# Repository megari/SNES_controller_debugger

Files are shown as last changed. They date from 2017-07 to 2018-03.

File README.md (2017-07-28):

SNES controller debugger
========================

This is a little project for debugging SNES controllers. The PCB design files
and the firmware source code are included.

The hardware uses an Atmel mega32u4 microcontroller.

The firmware uses the [YAAL](https://github.com/raphendyr/yaal) library and
[yaamake](https://github.com/raphendyr/yaamake). These are included as
submodules in the firmware/vendor directory.

Compilation of the firmware
---------------------------

The avr-gcc toolchain is required in order to compile the firmware. The
repositories of your distribution probably have this available.

After the toolchain has been installed:
```sh
cd firmware
```

If you haven't built yaamake yet, do so:
```sh
cd vendor/yaamake
make
cd ../..
```

Finally, build the firmware and program the board:
```sh
nano Makefile # Check that the programmer port is correct
make
make program
```

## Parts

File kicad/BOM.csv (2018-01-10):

Id | Designator | Package | Quantity | Designation | Supplier and ref
1 | H4,H3,H2,H1 | MountingHole_3.4mm | 4
2 | U1 | TQFP-44_10x10mm_Pitch0.8mm | 1 | ATmega32U4
3 | C1,C6 | C_0603_HandSoldering | 2 | 0.1µF
4 | C2,C3 | C_0603_HandSoldering | 2 | 22pF
5 | C4,C5,C7 | C_0603_HandSoldering | 3 | 1µF
6 | R1 | R_0603_HandSoldering | 1 | 10k
7 | R2,R3 | R_0805_HandSoldering | 2 | 22
8 | RV1 | Potentiometer_Trimmer_Vishay_TS53YL | 1 | POT
9 | D1,D2 | D_SOD-123 | 2 | MBR0520
10 | F1 | R_0603_HandSoldering | 1 | 500mA
11 | SW1 | SW_PUSH_6mm | 1 | Reset
12 | Y1 | Crystal_SMD_5032-2pin_5.0x3.2mm_HandSoldering | 1 | 16MHz
13 | R4,R8 | R_0603_HandSoldering | 2 | 1M
14 | R5,R7 | R_0603_HandSoldering | 2 | 220
15 | R6 | R_0603_HandSoldering | 1 | 0
16 | DS1 | LCD_2004_Pitch2.54mm | 1 | LCD20X4
17 | J2 | SNES_controller_port | 1 | Controller
18 | J1 | Pin_Header_Straight_2x03_Pitch2.54mm | 1 | ICSP
19 | Q1 | SOT-23_Handsoldering | 1 | DMG2302UK-7
20 | Q2 | SOT-23_Handsoldering | 1 | DMP2215L-7
21 | J3 | Conn_USBmicro-B_Amphenol_10118194-0001LF | 1 | MICRO_USB

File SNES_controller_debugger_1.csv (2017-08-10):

Id | Designator | Package | Quantity | Designation | Supplier and ref
1 | DS1 | LCD_2004_Pitch2.54mm | 1 | LCD20X4
2 | J1 | Pin_Header_Straight_2x03_Pitch2.54mm | 1 | ICSP
3 | U1 | TQFP-44_10x10mm_Pitch0.8mm | 1 | ATmega32U4
4 | C1,C6 | C_0603_HandSoldering | 2 | 0.1µF
5 | C2,C3 | C_0603_HandSoldering | 2 | 22pF
6 | C4,C5,C7 | C_0603_HandSoldering | 3 | 1µF
7 | J3 | Conn_USBmicro-B_Amphenol_10118194-0001LF | 1 | MICRO_USB
8 | R1 | R_0603_HandSoldering | 1 | 10k
9 | R2,R3 | R_0805_HandSoldering | 2 | 22
10 | RV1 | Potentiometer_Trimmer_Vishay_TS53YL | 1 | POT
11 | J2 | SNES_controller_port | 1 | CONTROLLER_OUT
12 | D1,D2 | D_SOD-123 | 2 | MBR0520
13 | F1 | R_0603_HandSoldering | 1 | 500mA
14 | SW1 | SW_PUSH_6mm | 1 | Reset_switch
15 | Y1 | Crystal_SMD_5032-2pin_5.0x3.2mm_HandSoldering | 1 | 16MHz
16 | Q1,Q2 | SOT-23 | 2 | DMG2302UK-7
17 | R4,R8 | R_0603_HandSoldering | 2 | 1M
18 | R5,R7 | R_0603_HandSoldering | 2 | 220
19 | R6 | R_0603_HandSoldering | 1 | 0

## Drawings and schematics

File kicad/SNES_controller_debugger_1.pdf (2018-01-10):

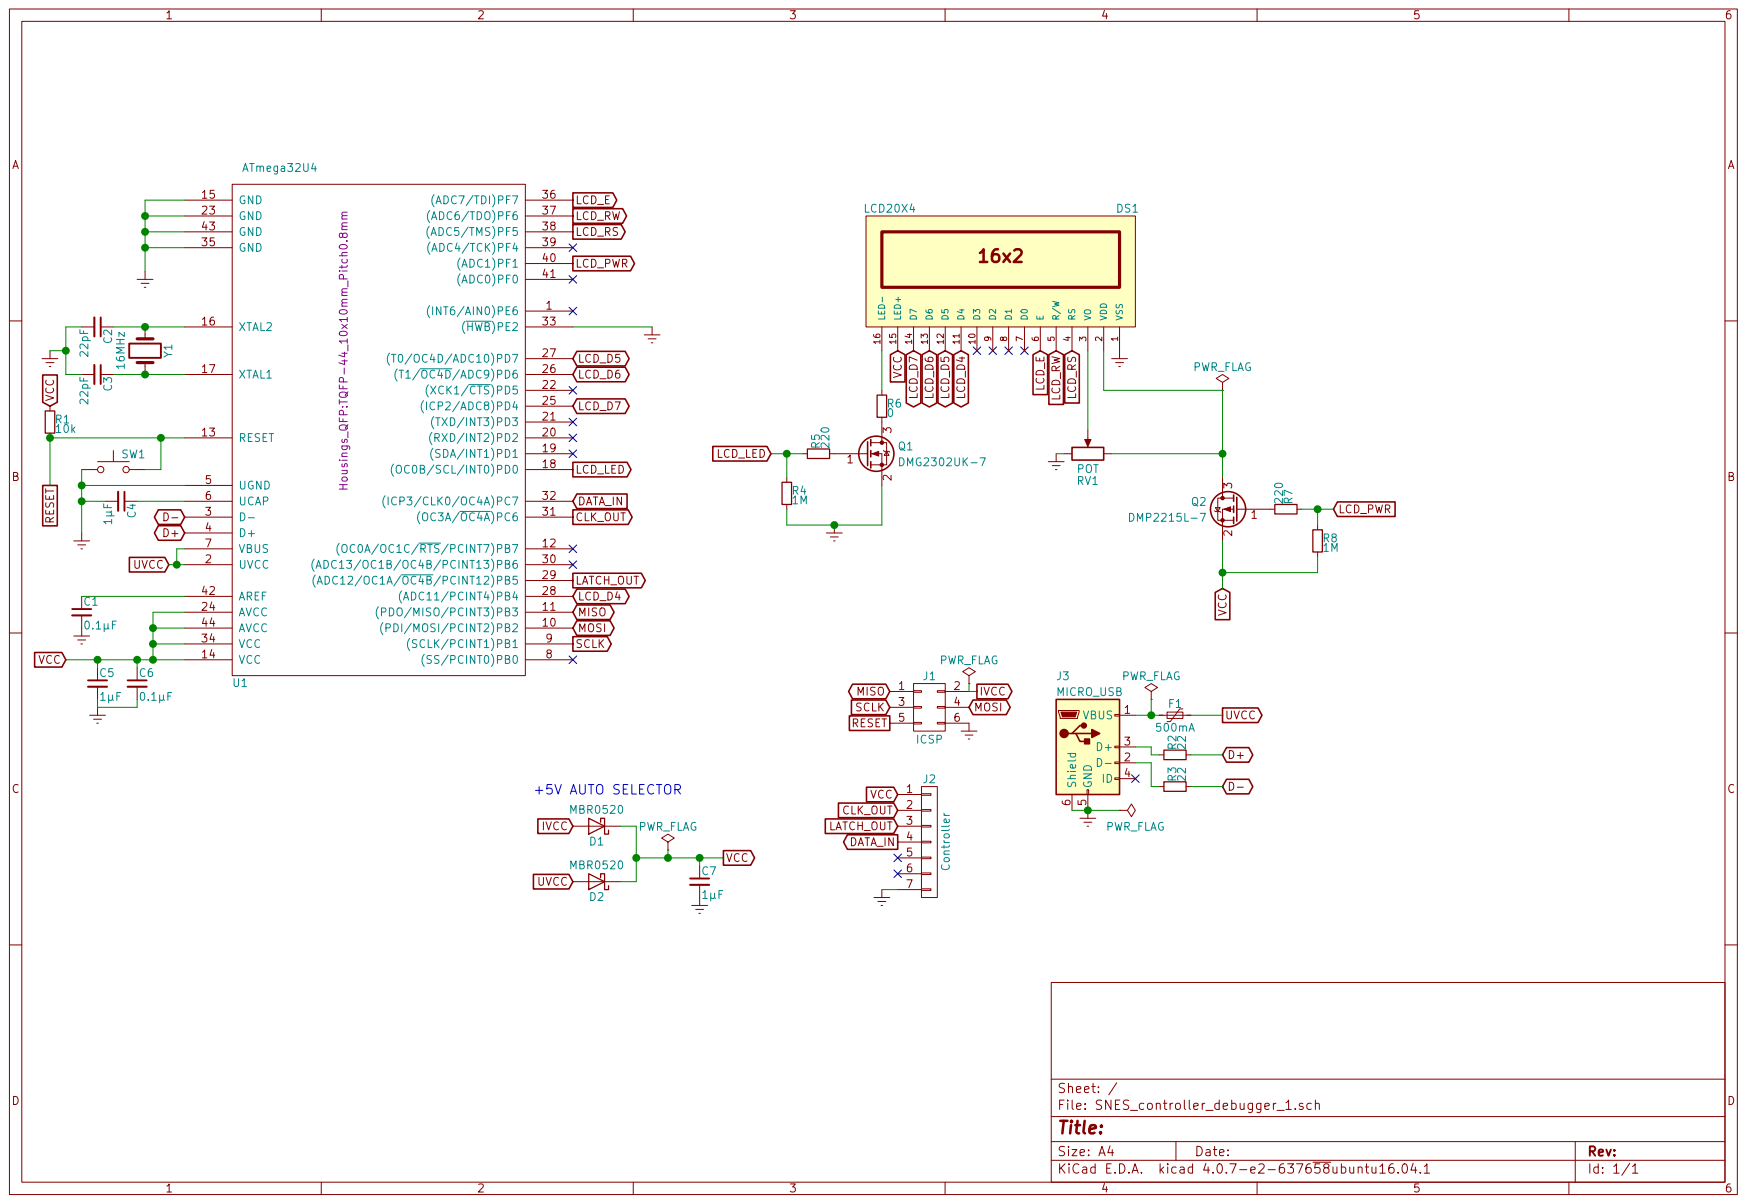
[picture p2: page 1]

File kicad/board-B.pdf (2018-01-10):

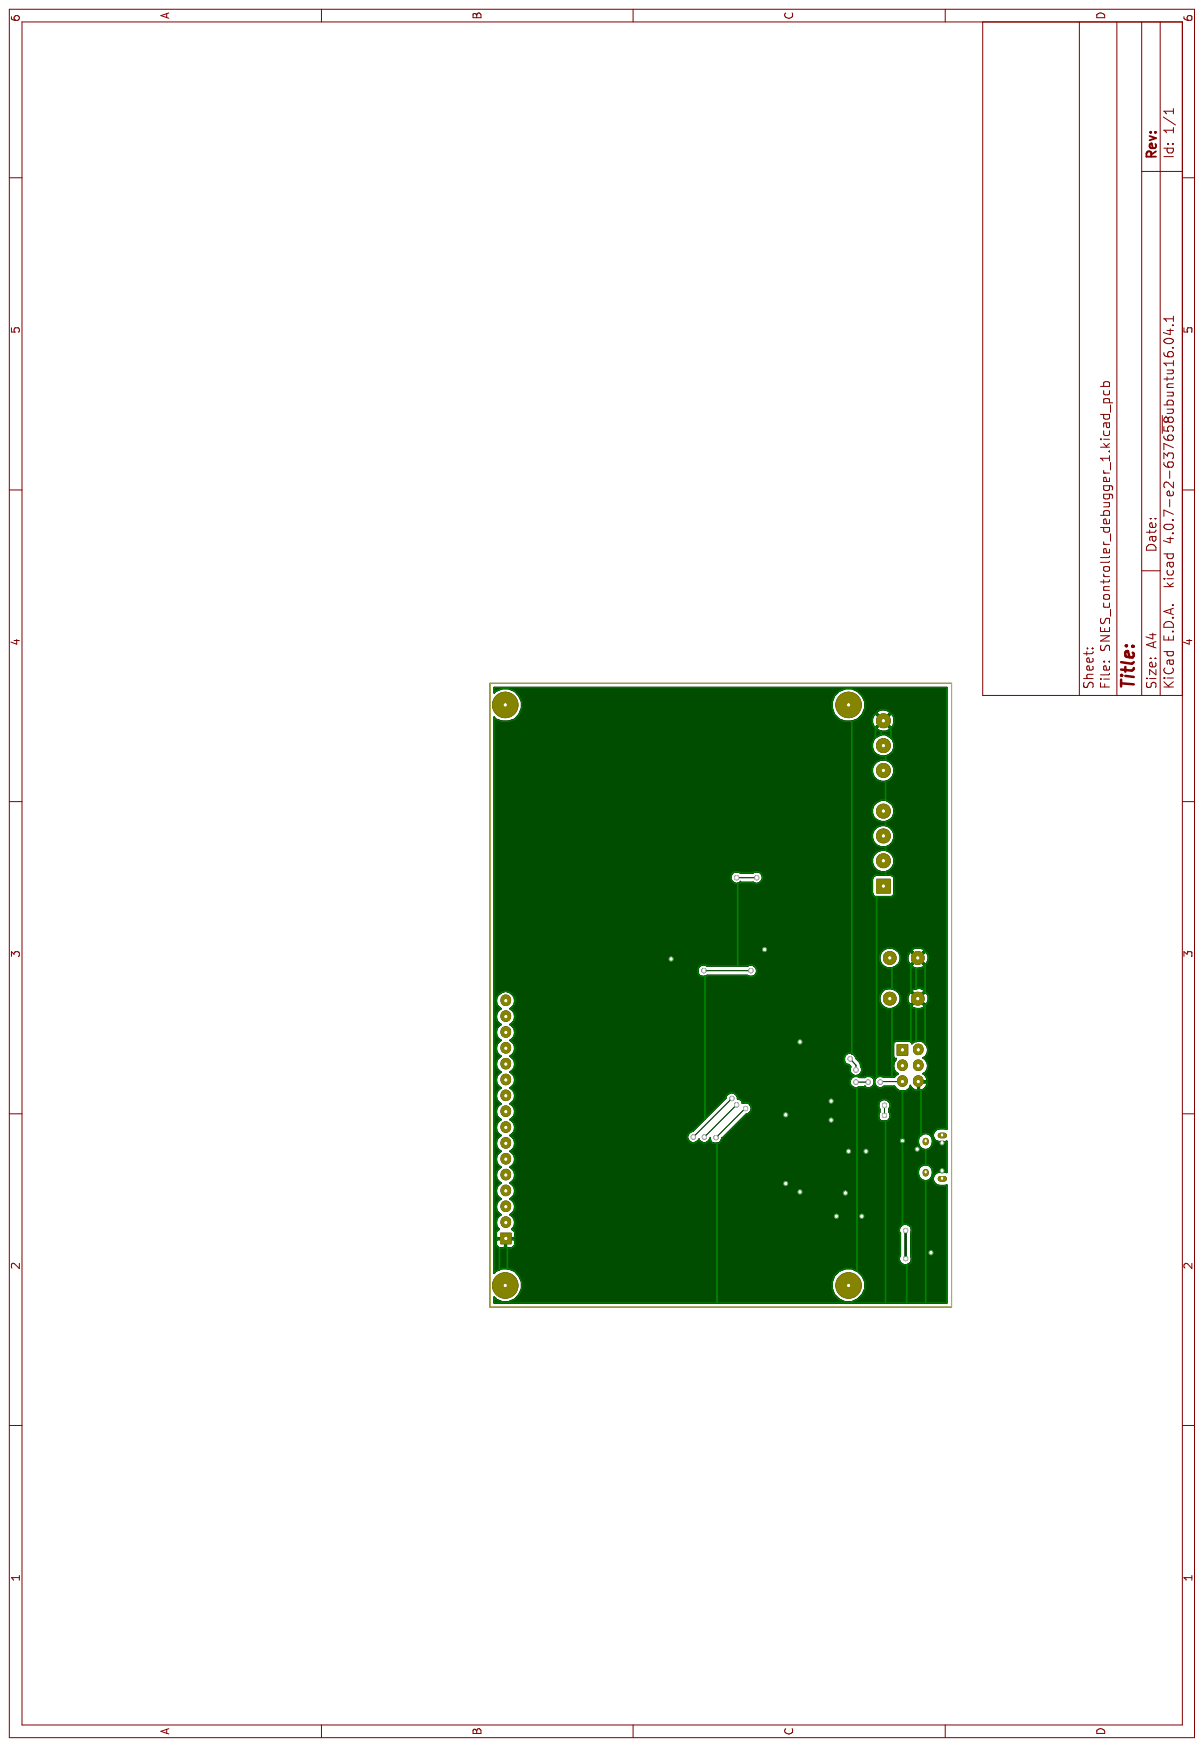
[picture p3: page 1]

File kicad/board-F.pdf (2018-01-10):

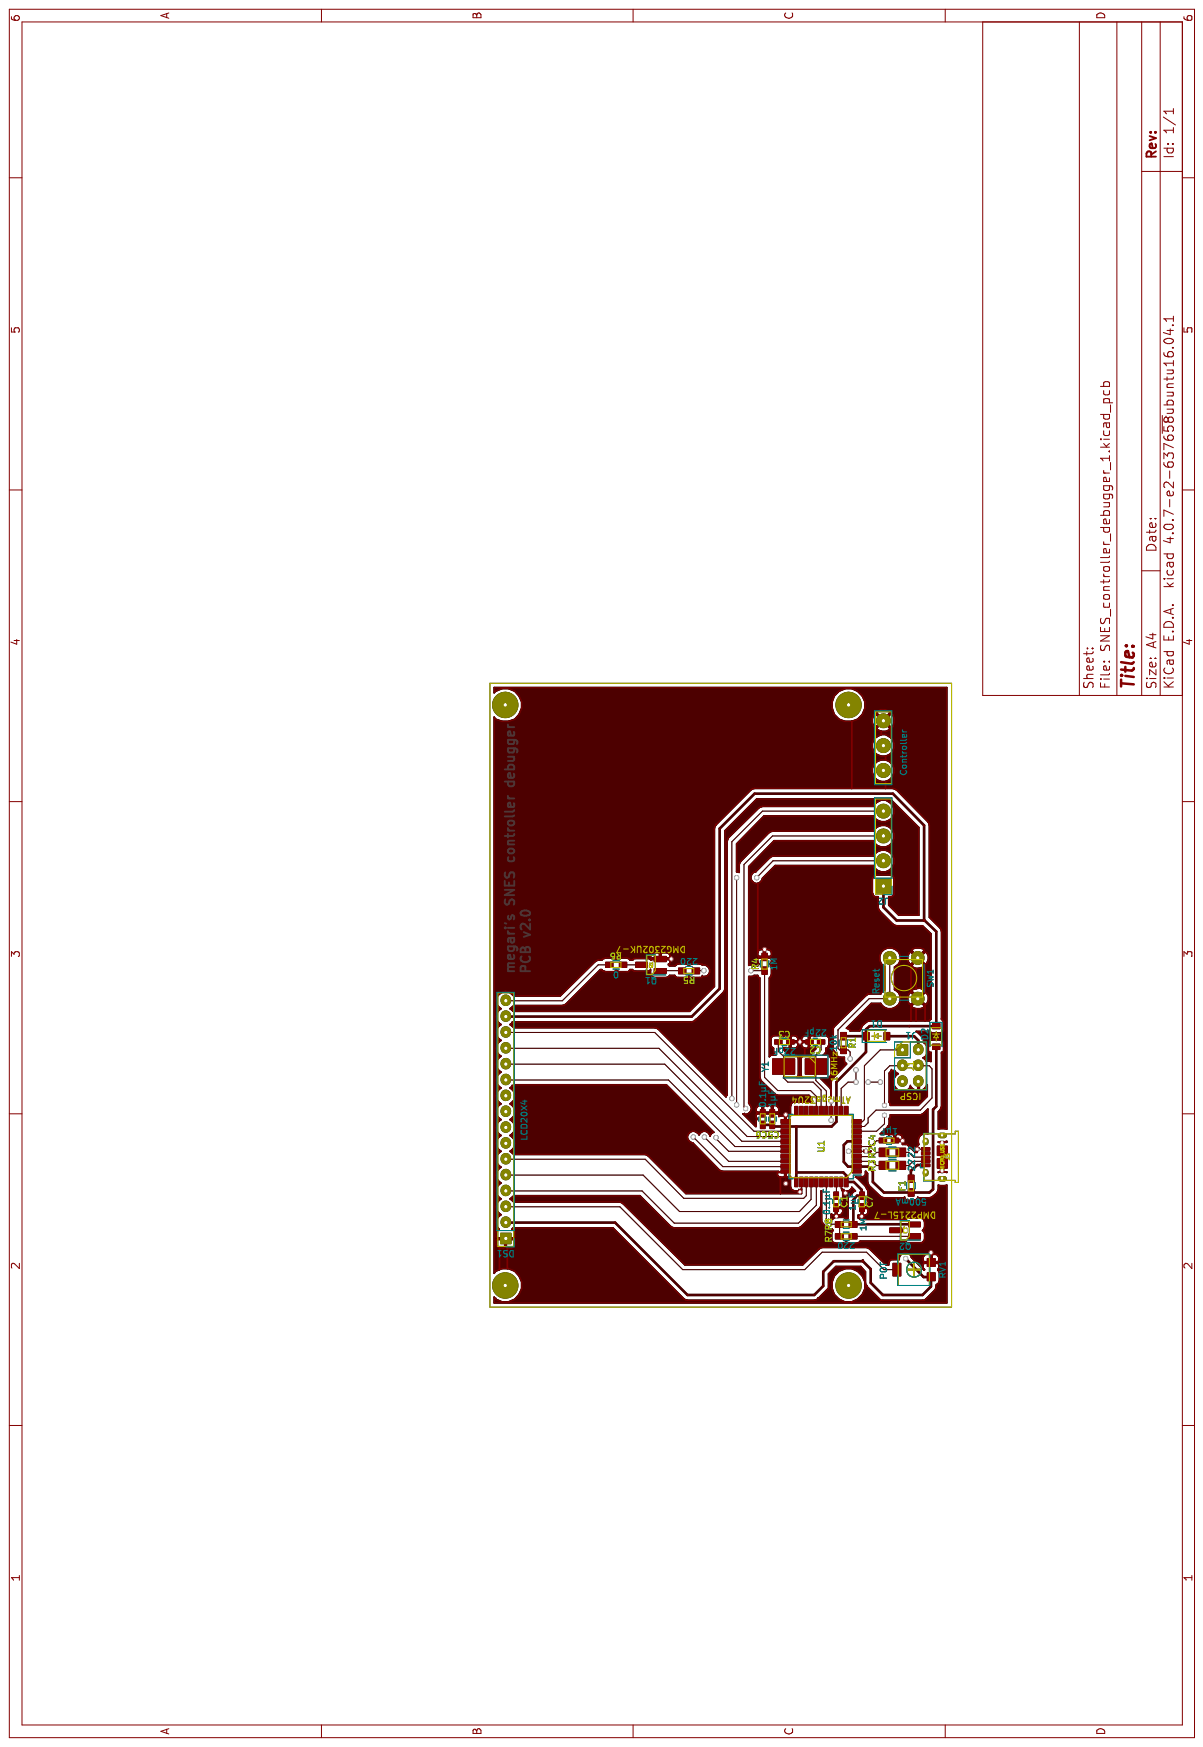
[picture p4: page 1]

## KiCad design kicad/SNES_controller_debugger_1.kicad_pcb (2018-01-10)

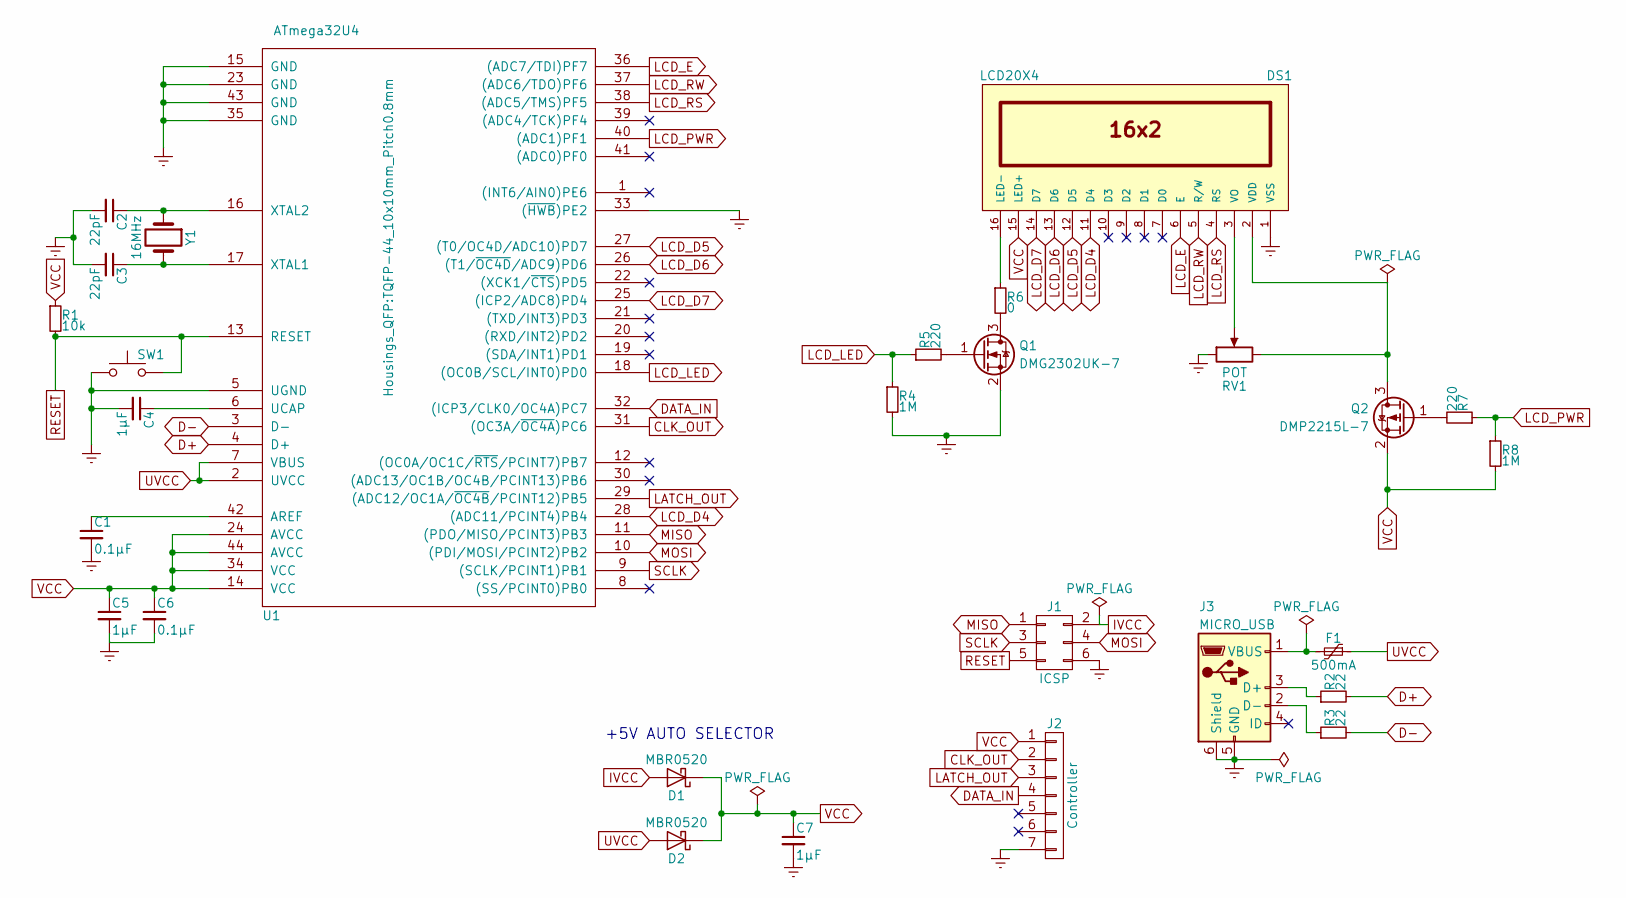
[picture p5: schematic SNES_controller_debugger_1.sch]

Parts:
C1, C6: 0.1µF; C_0603_HandSoldering
C2, C3: 22pF; C_0603_HandSoldering
C4, C5, C7: 1µF; C_0603_HandSoldering
D1, D2: MBR0520; D_SOD-123
DS1: LCD20X4; LCD_2004_Pitch2.54mm
F1: 500mA; R_0603_HandSoldering
J1: ICSP; Pin_Header_Straight_2x03_Pitch2.54mm
J2: Controller; SNES_controller_port
J3: MICRO_USB; Conn_USBmicro-B_Amphenol_10118194-0001LF; MPN 10118194-0001LF; Digi-Key part number 609-4618-1-ND
Q1: DMG2302UK-7; SOT-23_Handsoldering
Q2: DMP2215L-7; SOT-23_Handsoldering
R1: 10k; R_0603_HandSoldering
R2, R3: 22; R_0805_HandSoldering
R4, R8: 1M; R_0603_HandSoldering
R5, R7: 220; R_0603_HandSoldering
R6: 0; R_0603_HandSoldering
RV1: POT; Potentiometer_Trimmer_Vishay_TS53YL; MPN TS53YL103MR10; Digi-Key part number TS53YL-10KCT-ND
SW1: Reset; SW_PUSH_6mm; MPN MJTP1230; Digi-Key part number 679-2428-ND
U1: ATmega32U4; TQFP-44_10x10mm_Pitch0.8mm; MPN ATMEGA32U4-AU; Digi-Key part number ATMEGA32U4-AU-ND
Y1: 16MHz; Crystal_SMD_5032-2pin_5.0x3.2mm_HandSoldering; MPN NX5032GA-16MHZ-STD-CSK-4; Digi-Key part number 644-1187-1-ND

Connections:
CLK_OUT: J2.2, U1.31 ((OC3A/~OC4A~)PC6)
D+: R2.2, U1.4 (D+)
D-: R3.2, U1.3 (D-)
DATA_IN: J2.4, U1.32 ((ICP3/CLK0/OC4A)PC7)
Earth: C1.2, C2.2, C3.2, C4.2, C5.2, C6.2, C7.2, DS1.1 (VSS), J1.6, J2.7, J3.5 (GND), J3.6 (Shield), Q1.2 (S), R4.2, RV1.1, SW1.1, U1.5 (UGND), U1.15 (GND), U1.23 (GND), U1.33 ((~HWB~)PE2), U1.35 (GND), U1.43 (GND)
IVCC: D1.2 (A), J1.2
LATCH_OUT: J2.3, U1.29 ((ADC12/OC1A/~OC4B~/PCINT12)PB5)
LCD_D4: DS1.11 (D4), U1.28 ((ADC11/PCINT4)PB4)
LCD_D5: DS1.12 (D5), U1.27 ((T0/OC4D/ADC10)PD7)
LCD_D6: DS1.13 (D6), U1.26 ((T1/~OC4D~/ADC9)PD6)
LCD_D7: DS1.14 (D7), U1.25 ((ICP2/ADC8)PD4)
LCD_E: DS1.6 (E), U1.36 ((ADC7/TDI)PF7)
LCD_LED: R4.1, R5.1, U1.18 ((OC0B/SCL/INT0)PD0)
LCD_PWR: R7.1, R8.1, U1.40 ((ADC1)PF1)
LCD_RS: DS1.4 (RS), U1.38 ((ADC5/TMS)PF5)
LCD_RW: DS1.5 (R/W), U1.37 ((ADC6/TDO)PF6)
MISO: J1.1, U1.11 ((PDO/MISO/PCINT3)PB3)
MOSI: J1.4, U1.10 ((PDI/MOSI/PCINT2)PB2)
unnamed: C1.1, U1.42 (AREF)
unnamed: C2.1, U1.16 (XTAL2), Y1.1
unnamed: C3.1, U1.17 (XTAL1), Y1.2
unnamed: C4.1, U1.6 (UCAP)
unnamed: DS1.2 (VDD), Q2.3 (D), RV1.3
unnamed: DS1.3 (VO), RV1.2
unnamed: DS1.16 (LED-), R6.1
unnamed: F1.2, J3.1 (VBUS)
unnamed: J3.2 (D-), R3.1
unnamed: J3.3 (D+), R2.1
unnamed: Q1.1 (G), R5.2
unnamed: Q1.3 (D), R6.2
unnamed: Q2.1 (G), R7.2
RESET: J1.5, R1.2, SW1.2, U1.13 (RESET)
SCLK: J1.3, U1.9 ((SCLK/PCINT1)PB1)
UVCC: D2.2 (A), F1.1, U1.2 (UVCC), U1.7 (VBUS)
VCC: C5.1, C6.1, C7.1, D1.1 (K), D2.1 (K), DS1.15 (LED+), J2.1, Q2.2 (S), R1.1, R8.2, U1.14 (VCC), U1.24 (AVCC), U1.34 (VCC), U1.44 (AVCC)

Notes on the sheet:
+5V AUTO SELECTOR

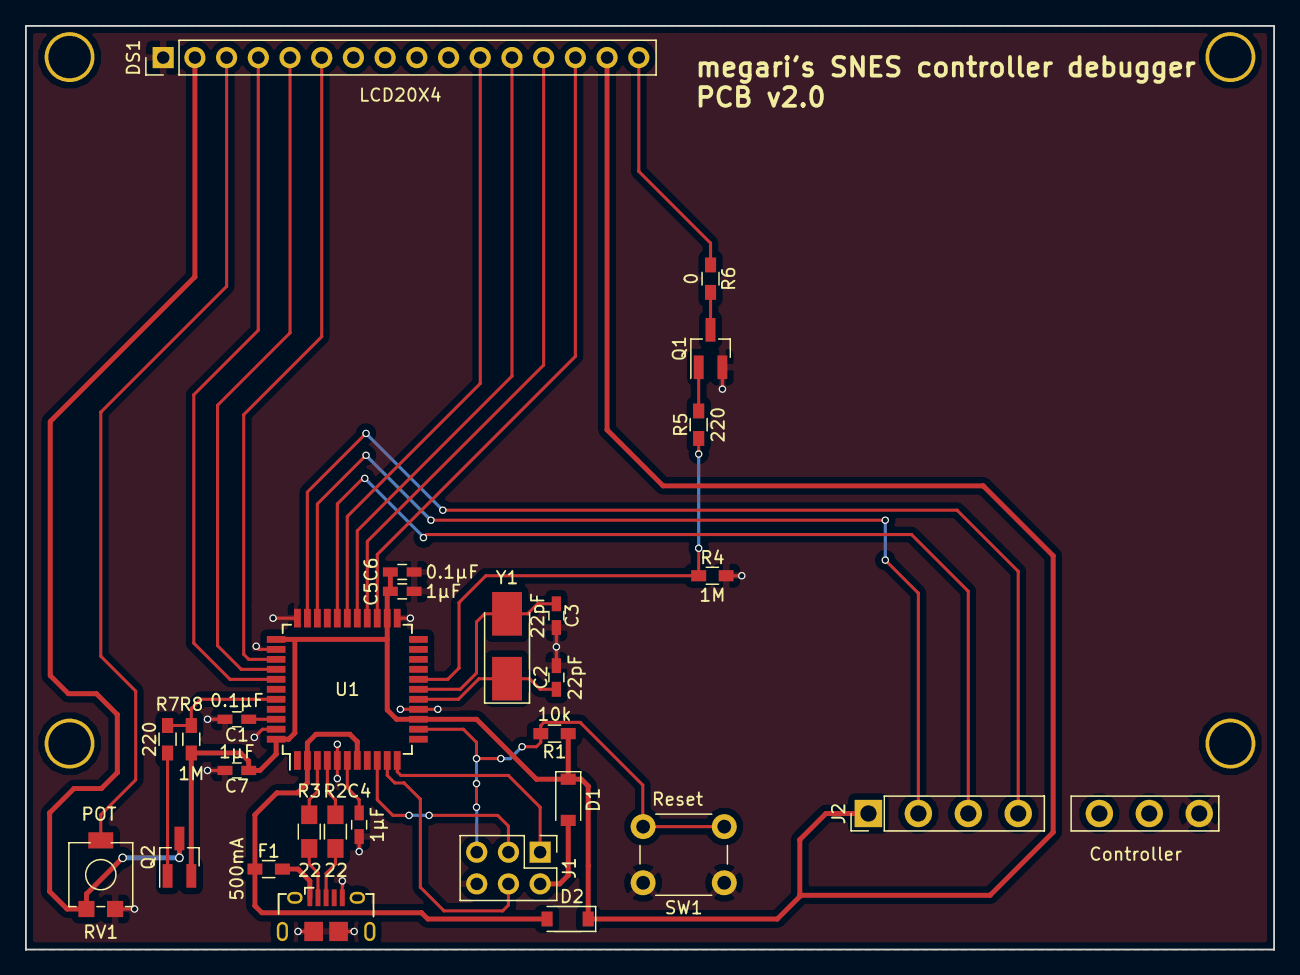
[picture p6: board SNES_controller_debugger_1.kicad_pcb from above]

Board: 2 copper layers, 100.0 x 74.0 mm, 32 parts (0 on the bottom side), 35 nets.

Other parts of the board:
H1, H2, H3, H4: MountingHole_3.4mm

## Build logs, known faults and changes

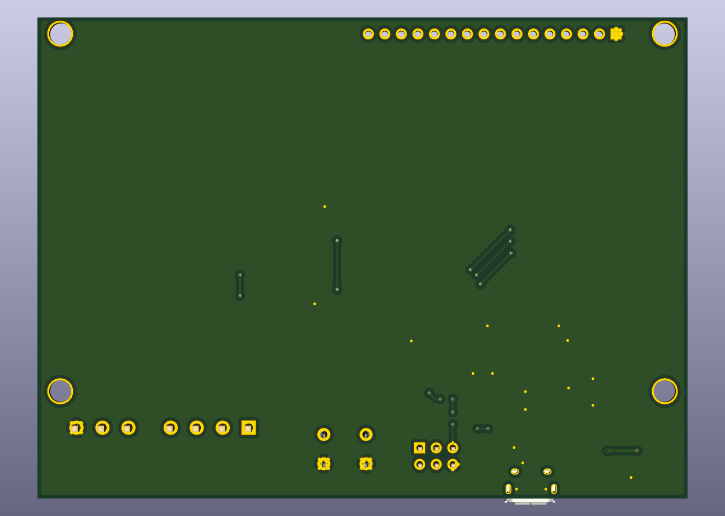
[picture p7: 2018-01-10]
kicad/SNES_controller_debugger_1_back.png

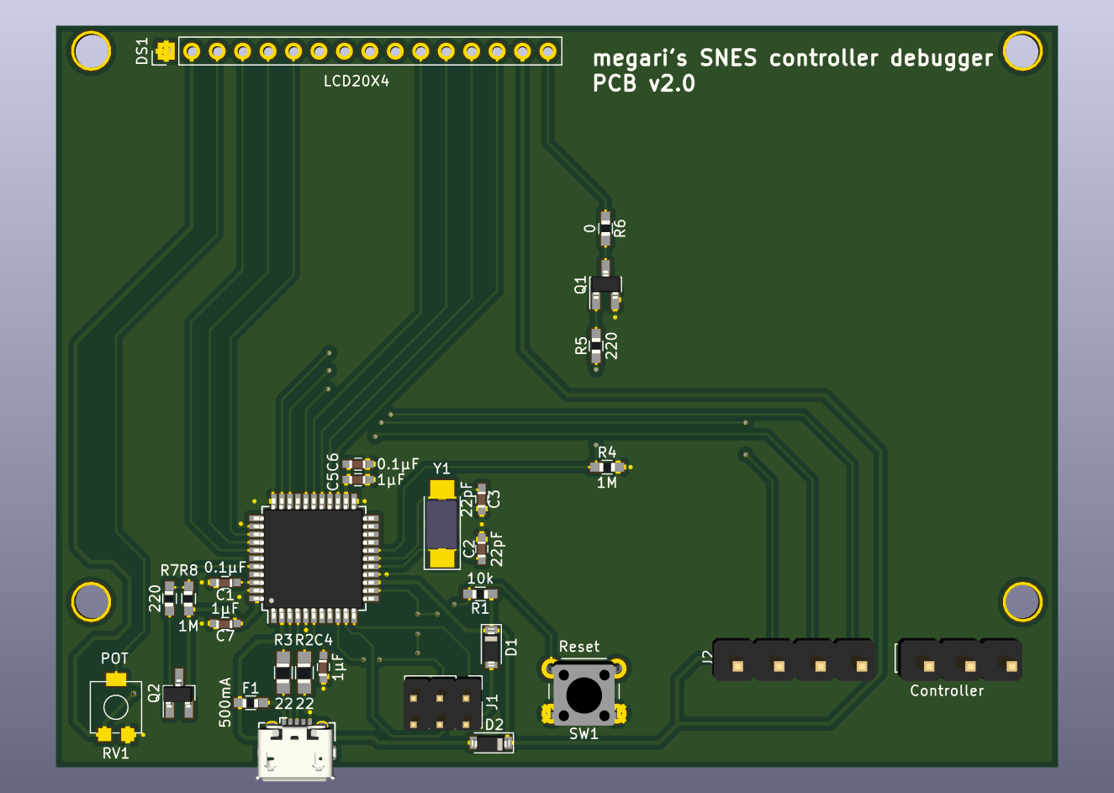
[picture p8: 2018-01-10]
kicad/SNES_controller_debugger_1_front.png

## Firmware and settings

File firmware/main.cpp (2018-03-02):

#include <yaal/io/ports.hh>
#include <yaal/devices/lcd_hd44780.hh>
#include <yaal/types/pinset.hh>

using namespace yaal;

template<typename PIN, bool polarity = true>
class PowerPin {
    PIN pin;

public:
    PowerPin() {
        pin.mode = OUTPUT;
        pin = polarity; // Initially on
    }

    void power(bool on) {
        /*
         * Truth table:
         *
         * polarity |  on | polarity ^ on | pin | power
         * ---------+-----+---------------+-----+------
         *     T    |  T  |       F       |  T  |  ON
         *     T    |  F  |       T       |  F  |  OFF
         *     F    |  T  |       T       |  F  |  ON
         *     F    |  F  |       F       |  T  |  OFF
         *
         */
        pin = !(polarity ^ on);
    }
};

template<bool polarity>
class PowerPin<NullPin, polarity> {
public:
    void power(bool) { }
};

class Backlight {
    uint8_t value;
    PortD0 pin;

    void reset(uint8_t val) {
        pin.mode = OUTPUT;

        // Fast PWM, non-inverting mode on OC0B (PortD0).
        // Use a prescaler of 64 to get a bit shy of 1000 Hz.
        TCCR0A = _BV(COM0B1) | _BV(WGM00) | _BV(WGM01);
        TCCR0B = 0;
        TCNT0 = 0;
        value = val;
        OCR0B = val;
        TCCR0B = _BV(CS00) | _BV(CS01);
    }
public:
    Backlight(uint8_t val = 0xff) : value(val) {
        reset(value);
    }

    void set(uint8_t val) {
        if (val == 0) { // Avoid the single spike
            TCCR0A = 0;
            TCCR0B = 0;
            pin = false;
            value = val;
        }
        else if (value == 0)
            reset(val);
        else {
            value = val;
            OCR0B = val;
        }
    }
};

enum SNES_button {
    BUTTON_B      = 0,
    BUTTON_Y      = 1,
    BUTTON_SELECT = 2,
    BUTTON_START  = 3,
    BUTTON_UP     = 4,
    BUTTON_DOWN   = 5,
    BUTTON_LEFT   = 6,
    BUTTON_RIGHT  = 7,
    BUTTON_A      = 8,
    BUTTON_X      = 9,
    BUTTON_L      = 10,
    BUTTON_R      = 11,
    BUTTON_NONE1  = 12,
    BUTTON_NONE2  = 13,
    BUTTON_NONE3  = 14,
    BUTTON_NONE4  = 15,
    VALID_BUTTON_MASK = (1 << BUTTON_NONE1) - 1,
};

volatile uint16_t buttons = 0;
volatile uint8_t clock_count = 0;
volatile bool clock_running = false;

enum Region : bool {
    REGION_NTSC = false,
    REGION_PAL  = true,
};
volatile Region region;

// Dim LCD backlight after 10 seconds, turn it off after 30 seconds.
volatile uint16_t idle_count = 0;
#define IDLE_DIM 600
#define IDLE_MAX 1800

/*
 * Some notes:
 * In a PAL controller, there are two pull-up resistors: R1 and R2.
 * R1 pulls the data clock high. About 1.1 kohm.
 * R2 pulls the data latch high. About 2.45 kohm.
 * There are also two "strips resistors" (for the lack of a better term) through
 * which the data clock and data latch go through to the shift register. These
 * seem to be about 240-280 ohm. Let's call them RX and RY.
 * Let's call the clock and latch inputs of the shift register CHIP_CLK_IN and
 * CHIP_LATCH_IN, respectively.
 *
 *  CHIP_CLK_IN        CHIP_LATCH_IN
 *            |        |
 *            RX       RY
 *            |        |
 * 5V--+--R1--+--CLK   |
 *     |               |
 *     |      +--------+
 *     |      |
 *     +--R2--+--LATCH
 *
 * On the console side we have as follows:
 * - PAL SNES
 *   - clock and latch can *not* be pulled up by the console (diodes prevent
 *     this)
 *   - clock and latch *can* be pulled down by the console
 *   - PAL controllers work fine
 *     - When latch or clock is high on the console side, the controller side
 *       pull-up resistors pull it high on the controller side
 *     - When latch or clock is low on the console side, the console pulls them
 *       down on the controller side as well
 *   - NTSC controllers do not work because they do not pull anything up
 *     - When the latch or clock is high on the console side, both appear as
 *       tri-state/low on the controller side
 *     - When the latch or clock is low on the console side, it is also low on
 *       the controller side
 * - NTSC SNES
 *   - clock and latch can be pulled both up and down by the console
 *   - PAL controllers work fine
 *     - When the latch or clock is high on the console side, both the console
 *       and the controller are pulling it up
 *     - When the latch or clock is low on the console side, the controller can
 *       not pull it up
 *   - NTSC controllers work fine
 *     - The console completely controls whether the latch or clock is high or
 *       low
 */

// Called on the rising edge of the latch pulse.
// Nothing here (yet?).
ISR(TIMER1_COMPA_vect) {
    ;
}

// Called on the falling edge of the latch pulse.
// This is when the controller starts outputting the state of the first button.
ISR(TIMER1_OVF_vect) {
    // Start the timer for the clock in non-inverting fast PWM mode,
    // with no prescaler.
    // Be sure to to enable the pull-up before changing the direction
    // of the pin, as otherwise the clock will glitch and confuse the
    // controller.
    PORTC |= _BV(PORTC6);
    DDRC |= _BV(DDC6);
    TCCR3A |= _BV(COM3A1);
    TCCR3B |= _BV(CS30);
    clock_running = true;

    buttons = 0;
}

// Called on the falling edge of the clock.
// This is when we sample the buttons.
ISR(TIMER3_COMPA_vect) {
    // Read the controller.
    buttons |= (!(PINC & _BV(PINC7))) << clock_count;
}

// Called on the rising edge of the clock.
ISR(TIMER3_OVF_vect) {
    if (++clock_count == 16) {
        // Stop the timer and reset everything.
        TCCR3A &= ~(_BV(COM3A1));
        TCCR3B &= ~(_BV(CS30));
        TCNT3 = 0;

        // We need to set the pin low before setting the direction
        // to input, for some reason - otherwise subsequent reads
        // from PINC will just report a high logic level even if
        // nothing is driving the pin high!
        PORTC &= ~_BV(PORTC6);
        DDRC &= ~_BV(DDC6);

        clock_running = false;
        clock_count = 0;

        if (idle_count < IDLE_MAX && !(buttons & VALID_BUTTON_MASK))
            idle_count++;
        else if (buttons & VALID_BUTTON_MASK) {
            if (idle_count > 0) {
                idle_count = 0;
            }
        }
    }
}

static void setup_latch() {
    // Set OC1A as an output and set its state to low.
    // OC1A is PB5 on atmega2560. In Arduino terms, digital pin 11.
    // OC1A is PB5 on atmega32u4. In Arduino terms, digital pin 9.
    DDRB |= _BV(DDB5);
    PORTB &= ~(_BV(PORTB5));

    // Set fast PWM in inverting mode, using ICR1 as TOP.
    // Keep the timer stopped for now.
    TCCR1A = _BV(COM1A0) | _BV(COM1A1) | _BV(WGM11);
    TCCR1B = _BV(WGM12) | _BV(WGM13);
    TCNT1 = 0;

    // Enable the Timer 1 Output Compare A Match and Overflow interrupts.
    // This way we get an interrupt on both the rising and the falling edge of
    // the latch pulse.
    TIMSK1 = _BV(OCIE1A) | _BV(TOIE1);

    /*
     * Input the parameters for 60 Hz with a pulse width of 12 µs, using an
     * appropriate prescaler. Setting the prescaler starts the timer.
     *
     * The formula to find out TOP:
     *     f_PWM = f_CLK_IO/(N * (1 + TOP))
     * <=> (1 + TOP) = f_CLK_IO/(N * f_PWM)
     * <=> TOP = f_CLK_IO/(N * f_PWM) - 1
     *
     * Let f_CLK_IO = 16000000,
     *     f_PWM = 60:
     *
     * TOP = 1600000/(6 * N) - 1
     *     = 800000/(3 * N) - 1
     *
     * TOP can be at most 65535. N is in {1, 8, 64, 256, 1024}.
     *
     * If N = 1:
     * TOP = 800000/3 - 1
     *    ~= 266666
     *     > 65535
     *
     * If N = 8:
     * TOP = 800000/24 - 1
     *    ~= 33333
     *    <= 65535
     *
     * N = 8 is first available option and it has the most precision of all.
     *
     * Now we have to find out what timer value corresponds to a 12 µs pulse
     * width.
     *
     * T_period = (TOP + 1)/(f_CLK_IO/N) s
     *          = 33334/2000000 s
     *          = 33334 * 1000000/2000000 µs
     *          = 33334/2 µs
     *          = 16667 µs
     *
     * timer_value = TOP - (TOP + 1) * (12 µs)/T_period
     *             = 33333 - 33334 * (12 µs)/(33334/2 µs)
     *             = 33333 - 24
     *             = 33309
     *
     */
    ICR1 = 33333;
    OCR1A = 33309;
}

static void start_latch() {
    // Start the timer with a prescaler of 8, as chosen above.
    TCCR1B |= _BV(CS11);
}

static void setup_clock() {
    // Set OC3A as an output and set its state to high.
    // OC3A is:
    //     - PE3 on atmega2560. In Arduino terms, digital pin 5.
    //     - PC6 on atmega32u4. In Arduino terms, digital pin 5.
    DDRC |= _BV(DDC6);
    PORTC |= _BV(PORTC6);

    // Set fast PWM, using ICR3 as TOP.
    // Keep the timer stopped for now.
    TCCR3A = _BV(WGM31);
    TCCR3B = _BV(WGM32) | _BV(WGM33);
    TCNT3 = 0;

    // Enable the Timer 3 Output Compare A Match and Overflow interrupts.
    // This way we get an interrupt on both the rising and the falling edge of
    // the clock pulse.
    TIMSK3 = _BV(OCIE3A) | _BV(TOIE3);

    /*
     * Input the parameters for:
     *     - Period: 12 µs
     *       => Frequency: 83333.33333... Hz
     *     - Pulse width: 6 µs
     *       => duty cycle: 50%
     *
     * The formula to find out TOP:
     *     f_PWM = f_CLK_IO/(N * (1 + TOP))
     * <=> (1 + TOP) = f_CLK_IO/(N * f_PWM)
     * <=> TOP = f_CLK_IO/(N * f_PWM) - 1
     *
     * Let f_CLK_IO = 16000000,
     *     f_PWM = 83333.33333...:
     *
     * TOP = 16000000/(83333.33333... * N) - 1
     *     = 192/N - 1
     *
     * TOP can be at most 65535. N is in {1, 8, 64, 256, 1024}. We can easily
     * just use N = 1:
     * TOP = 191
     *
     * Now we have to find out what timer value corresponds to a 6 µs pulse
     * width.
     *
     * T_period = (TOP + 1)/(f_CLK_IO/N) s
     *          = 192/16000000 s
     *          = 192 * 1000000/16000000 µs
     *          = 192/16 µs
     *          = 12 µs
     *
     * timer_value = (TOP + 1) * (6 µs)/T_period - 1
     *             = 192 * (6 µs)/(12 µs) - 1
     *             = 95
     *
     */
    ICR3 = 191;
    OCR3A = 95;
}

// D4-D7
typedef Pinset<PortB4, PortD7, PortD6, PortD4> FourBitSet;
// RS, RW, E
typedef PortF5 RSPin;
typedef PortF6 RWPin;
typedef PortF7 EPin;
Backlight backlight;
PowerPin<PortF1, false> power; // The polarity is inverted because of using a P-MOSFET.
typedef LCDInterface<RSPin, RWPin, EPin, FourBitSet> FourBitInterface;
// Use an LCD screen with 4 lines, 5x8 font
typedef LiquidCrystalHD44780<FourBitInterface, 4, false> LCD;

// Control the supply of power to the LCD.
static void lcd_power(bool on) {
    power.power(on);

    if (!on) {
        // Make sure the LCD is not powered by any of the I/O pins.
        RSPin rs;
        RWPin rw;
        EPin e;
        FourBitSet data;
        rs.mode = OUTPUT;
        rw.mode = OUTPUT;
        e.mode = OUTPUT;
        data.set_output();
        rs = false;
        rw = false;
        e = false;
        data = 0x00;
    }
}

static void lcd_backlight(uint8_t val) {
    backlight.set(val);
}

void main() {
    // Disable the USB controller. It generates a *lot* of interrupts after a
    // reset, for some reason.
    USBCON &= ~_BV(USBE);

    // Set PortC7 as input for reading the incoming controller data.
    // Enable pull-up resistors so that the readings show no buttons
    // pressed when there is no controller connected.
    DDRC &= ~(_BV(DDC7));
    PORTC |= _BV(PORTC7);

    // Disable interrupts globally while we configure PWM.
    cli();

    // Configure and start the latch pulse generation.
    setup_latch();

    // Configure the clock generation. Note that the clock is not started here.
    setup_clock();

    // Start the latch pulse generation.
    start_latch();

    // Re-enable interrupts globally.
    sei();

    // Turn the LCD screen off and on to re-initialize it if the MCU was reset.
    lcd_power(false);
    _delay_ms(100);
    lcd_power(true);
    _delay_ms(100);

    // Initialize the LCD screen.
    LCD lcd;
    lcd.setup();

    // Display on, cursor off, blink off.
    lcd.display_control(true, false, false);

    // Clear display.
    lcd.clear();

    // Set entry mode: increment, no shift.
    lcd.entry_mode(LCD::INCREMENT, false);

    // Create custom character glyphs for arrows representing the D-pad.
    constexpr uint8_t up_arrow = 0x00;
    constexpr uint8_t down_arrow = 0x01;
    constexpr uint8_t left_arrow = 0x02;
    constexpr uint8_t right_arrow = 0x03;
    const uint8_t arrow_glyphs[4][8] = {
        {
            0b00000,
            0b00100,
            0b01110,
            0b10101,
            0b00100,
            0b00100,
            0b00100,
            0b00000
        },
        {
            0b00000,
            0b00100,
            0b00100,
            0b00100,
            0b10101,
            0b01110,
            0b00100,
            0b00000
        },
        {
            0b00000,
            0b00100,
            0b01000,
            0b11111,
            0b01000,
            0b00100,
            0b00000,
            0b00000
        },
        {
            0b00000,
            0b00100,
            0b00010,
            0b11111,
            0b00010,
            0b00100,
            0b00000,
            0b00000
        }
    };

    // Set the first 4 glyphs in CGRAM to the arrows.
    for (uint8_t glyph = 0; glyph < 4; ++glyph) {
        lcd.set_cgram_addr(glyph * 8);
        for (uint8_t row = 0; row < 8; ++row)
            lcd.put_char(arrow_glyphs[glyph][row]);
    }

    // Now, draw the following (requires a 2004 LCD):
    //     L          R
    //  ^                X
    // < > SELECT START Y A
    //  v                B
    uint16_t buttons_saved;
    uint16_t idle_count_saved;
    enum {
        BL_ON,
        BL_DIMMED,
        BL_OFF,
    } backlight_state = BL_ON;
    while (1) {
        // Wait until we are in a period where the clock is not running.
        while (clock_running) ;

        cli();
        // Detect whether the controller has a pull-up resistor
        // for the clock line. If it does, it is a PAL controller.
        region = Region(!!(PINC & _BV(PINC6)));

        buttons_saved = buttons;
        idle_count_saved = idle_count;
        sei();
        buttons_saved &= VALID_BUTTON_MASK;

        // Dim the backlight and eventually turn it off if we're idle
        switch (backlight_state) {
        case BL_ON:
            if (idle_count_saved >= IDLE_DIM) {
                lcd_backlight(70);
                backlight_state = BL_DIMMED;
            }
            break;
        case BL_DIMMED:
            if (idle_count_saved == IDLE_MAX) {
                lcd.display_control(false, false, false);
                lcd_backlight(0);
                backlight_state = BL_OFF;
                break;
            }
            // Intentional fall-through
        case BL_OFF:
            if (idle_count_saved < IDLE_DIM) {
                lcd.display_control(true, false, false);
                lcd_backlight(255);
                backlight_state = BL_ON;
            }
            break;
        }

        if (backlight_state == BL_OFF)
            continue;

        // First row:
        lcd.set_cursor_pos(0, 4);
        if (buttons_saved & (1 << BUTTON_L))
            lcd.put_char('L');
        else
            lcd.put_char(' ');

#if 1
        lcd.set_cursor_pos(0, 8);
        if (region == REGION_PAL)
            lcd.put_string("PAL ");
        else
            lcd.put_string("NTSC");
#endif

        lcd.set_cursor_pos(0, 15);
        if (buttons_saved & (1 << BUTTON_R))
            lcd.put_char('R');
        else
            lcd.put_char(' ');

        // Second row:
        lcd.set_cursor_pos(1, 1);
        if (buttons_saved & (1 << BUTTON_UP))
            lcd.put_char(up_arrow);
        else
            lcd.put_char(' ');

        lcd.set_cursor_pos(1, 18);
        if (buttons_saved & (1 << BUTTON_X))
            lcd.put_char('X');
        else
            lcd.put_char(' ');

        // Third row:
        lcd.set_cursor_pos(2, 0);
        if (buttons_saved & (1 << BUTTON_LEFT))
            lcd.put_char(left_arrow);
        else
            lcd.put_char(' ');

        lcd.put_char(' ');
        if (buttons_saved & (1 << BUTTON_RIGHT))
            lcd.put_char(right_arrow);
        else
            lcd.put_char(' ');

        if (buttons_saved & (1 << BUTTON_SELECT))
            lcd.put_string(" SELECT ");
        else
            lcd.put_string("        ");

        if (buttons_saved & (1 << BUTTON_START))
            lcd.put_string("START ");
        else
            lcd.put_string("      ");

        lcd.set_cursor_pos(2, 17);
        if (buttons_saved & (1 << BUTTON_Y))
            lcd.put_char('Y');
        else
            lcd.put_char(' ');

        lcd.put_char(' ');
        if (buttons_saved & (1 << BUTTON_A))
            lcd.put_char('A');
        else
            lcd.put_char(' ');

        // Fourth row:
        lcd.set_cursor_pos(3, 1);
        if (buttons_saved & (1 << BUTTON_DOWN))
            lcd.put_char(down_arrow);
        else
            lcd.put_char(' ');

        lcd.set_cursor_pos(3, 18);
        if (buttons_saved & (1 << BUTTON_B))
            lcd.put_char('B');
        else
            lcd.put_char(' ');
    }
}

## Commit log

2017-08-04 pcb: Tweak USB traces, fill an area with a ground plane.
    [SNES_controller_debugger_1-B.Cu.gbr, SNES_controller_debugger_1-B.Mask.gbr, SNES_controller_debugger_1-B.SilkS.gbr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]
2017-08-05 pcb: Complete overhaul after getting some advice from an actual electronics engineer.
    [SNES_controller_debugger_1-B.Cu.gbr, SNES_controller_debugger_1-B.Mask.gbr, SNES_controller_debugger_1-B.SilkS.gbr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]
2017-08-05 pcb: Move C5 and C6 nearer to the MCU.
    [SNES_controller_debugger_1-B.Cu.gbr, SNES_controller_debugger_1-B.Mask.gbr, SNES_controller_debugger_1-B.SilkS.gbr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]
2017-08-06 pcb: Another complete overhaul under the supervision of Icchan^.
    [SNES_controller_debugger_1-B.Cu.gbr, SNES_controller_debugger_1-B.Mask.gbr, SNES_controller_debugger_1-B.SilkS.gbr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]
2017-08-07 pcb: Work on reducing the number and length of traces on the back side to make the ground plane more unified.
    [SNES_controller_debugger_1-B.Cu.gbr, SNES_controller_debugger_1-B.Mask.gbr, SNES_controller_debugger_1-B.SilkS.gbr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]
2017-08-08 pcb: Add Digi-Key part numbers and MPNs to some components
    [SNES_controller_debugger_1-B.Cu.gbr, SNES_controller_debugger_1-B.Mask.gbr, SNES_controller_debugger_1-B.SilkS.gbr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]
2017-08-10 pcb: Add hardware capability to dim the LCD backlight and to switch power to the LCD
    [SNES_controller_debugger_1-B.Cu.gbr, SNES_controller_debugger_1-B.Mask.gbr, SNES_controller_debugger_1-B.SilkS.gbr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]
2017-08-10 firmware: Adapt to changes in PCB version 2.0, toggle LCD off and on to re-initialize on reset
    [main.cpp]
2017-08-10 pcb: Update the BOM
    [SNES_controller_debugger_1.csv]
2017-08-11 pcb: Generate schema PDF
2017-08-15 firmware: Clean up LCD power and backlight control
2017-08-15 pcb, firmware: Using an N-MOSFET to cut power to the LCD from the negative side won't work, so use a P-MOSFET on the positive side
    [BOM.csv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]
2017-08-21 pcb: Tweak LCD screen footprint and a few traces
    [SNES_controller_debugger_1.kicad_pcb]
2017-08-25 firmware: Introduce the PowerPin class for controlling LCD power and backlight
2017-08-29 pcb: Add holes corresponding to where they are on the LCD, tweak some silkscreen texts
    [SNES_controller_debugger_1-B.Cu.gbr, SNES_controller_debugger_1-B.Mask.gbr, SNES_controller_debugger_1-B.SilkS.gbr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]
2017-10-09 pcb: Update gerbers, PDFs and PNGs
    [SNES_controller_debugger_1-B.Cu.gbr, SNES_controller_debugger_1-B.Mask.gbr, SNES_controller_debugger_1-B.SilkS.gbr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]
2017-10-12 pcb: Move all kicad files to their own separate directory
    [BOM.csv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]
2017-12-22 firmware: Implement PWM backlight control
2018-01-10 pcb: Fix/add some footprints
    [BOM.csv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]
